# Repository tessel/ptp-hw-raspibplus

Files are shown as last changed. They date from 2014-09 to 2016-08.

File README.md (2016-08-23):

**[UNMAINTAINED] This library does not have a maintainer. The source code and repository will be kept at this URL indefinitely. If you'd like to help maintain this codebase, create an issue on this repo explaining why you'd like to become a maintainer and tag @tessel/maintainers in the body.**

ptp-hw-raspibplus
==================
Hardware adaptor to allow Tessel modules to be used with a Raspberry Pi B+ in conjunction with the Portable Tessel Platform (PTP).

Designs in KiCad.

### License

Copyright 2014 Technical Machine, Inc.
CC-BY-SA

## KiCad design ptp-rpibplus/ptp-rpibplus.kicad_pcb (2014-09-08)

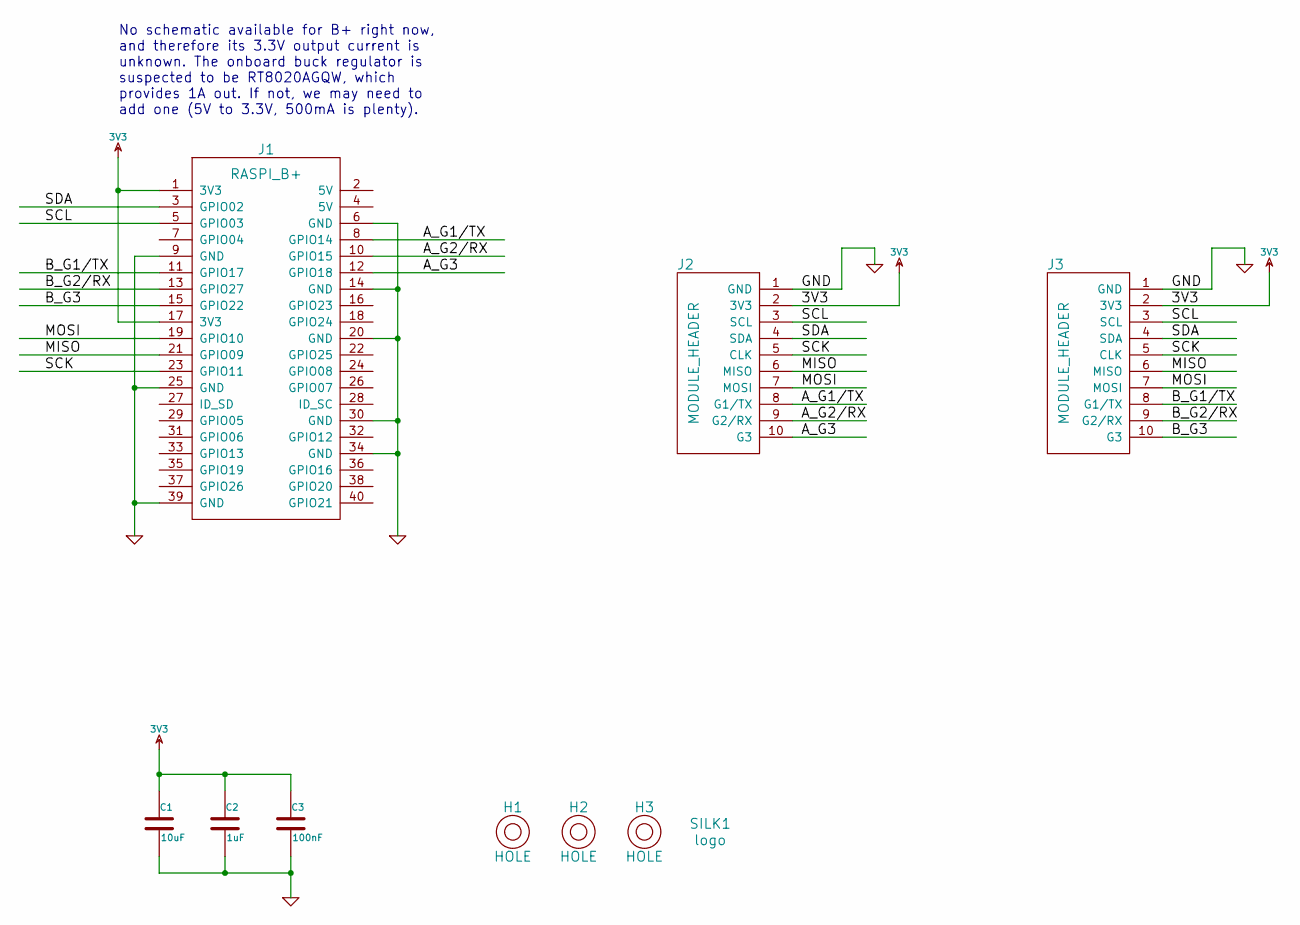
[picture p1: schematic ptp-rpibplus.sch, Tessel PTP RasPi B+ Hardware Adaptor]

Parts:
C1: 10uF; c_0805
C2: 1uF; c_0402
C3: 100nF; c_0402
H1, H2, H3: HOLE; HOLE-2.75mm-6.2mm
J1: RASPI_B+; Pin_Header_Straight_2x20
J2, J3: MODULE_HEADER; MODULE_HEADER_TESSEL
SILK1: logo; PTP-RPI-LOGO

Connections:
3V3: C1.1, C2.1, C3.1, J1.1 (3V3), J1.17 (3V3), J2.2 (3V3), J3.2 (3V3)
/A_G1/TX: J1.8 (GPIO14), J2.8 (G1/TX)
/A_G2/RX: J1.10 (GPIO15), J2.9 (G2/RX)
/A_G3: J1.12 (GPIO18), J2.10 (G3)
/B_G1/TX: J1.11 (GPIO17), J3.8 (G1/TX)
/B_G2/RX: J1.13 (GPIO27), J3.9 (G2/RX)
/B_G3: J1.15 (GPIO22), J3.10 (G3)
/MISO: J1.21 (GPIO09), J2.6 (MISO), J3.6 (MISO)
/MOSI: J1.19 (GPIO10), J2.7 (MOSI), J3.7 (MOSI)
/SCK: J1.23 (GPIO11), J2.5 (CLK), J3.5 (CLK)
/SCL: J1.5 (GPIO03), J2.3 (SCL), J3.3 (SCL)
/SDA: J1.3 (GPIO02), J2.4 (SDA), J3.4 (SDA)
GND: C1.2, C2.2, C3.2, J1.6 (GND), J1.9 (GND), J1.14 (GND), J1.20 (GND), J1.25 (GND), J1.30 (GND), J1.34 (GND), J1.39 (GND), J2.1 (GND), J3.1 (GND)

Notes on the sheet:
No schematic available for B+ right now, and therefore its 3.3V output current is unknown. The onboard buck regulator is suspected to be RT8020AGQW, which provides 1A out. If not, we may need to add one (5V to 3.3V, 500mA is plenty).

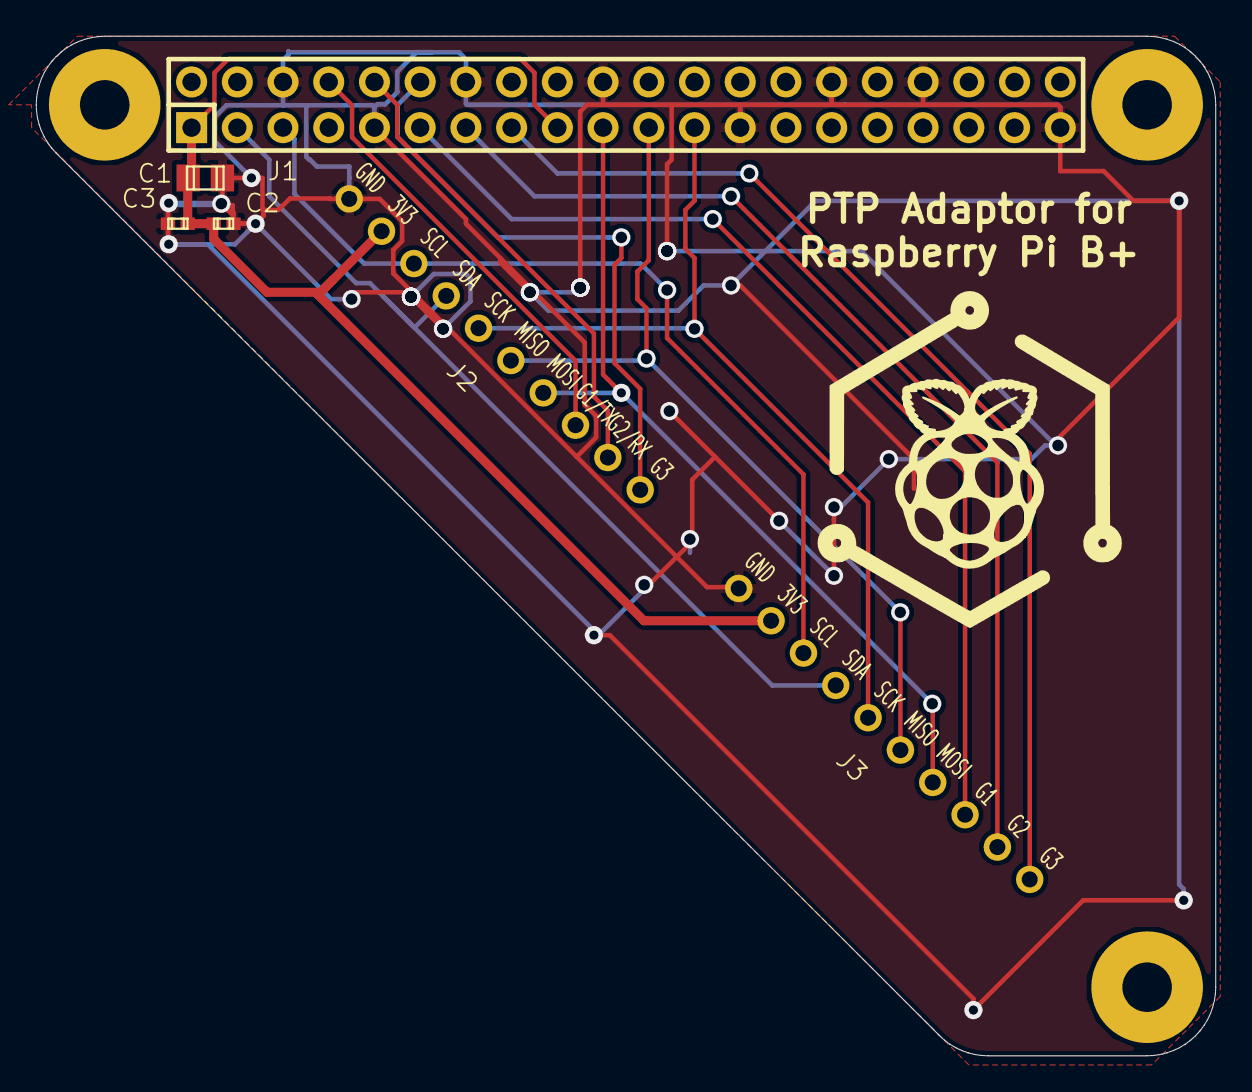
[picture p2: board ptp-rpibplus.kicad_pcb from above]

Board: 2 copper layers, 65.5 x 56.6 mm, 10 parts (0 on the bottom side), 13 nets.

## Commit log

2014-08-20 raspi module for ptp
    [tessel-raspi-b-plus.brd, tessel-raspi-b-plus.sch]
2014-08-22 added silkscreen text
    fixed repo
    Create README.md
    [tessel-raspi-b-plus.brd]
2014-09-05 wipe for kicad
    [tessel-raspi-b-plus.brd, tessel-raspi-b-plus.sch]
2014-09-05 started kicad project, schem
    [ptp-rpibplus.sch]
2014-09-05 parts in schematic, gotta do footprints
2014-09-05 schematic first pass
    [ptp-rpibplus.sch]
2014-09-05 netlist, annotation
    [ptp-rpibplus.sch]
2014-09-05 board file exists, components are all on it...rpi silk is no good
    [ptp-rpibplus.kicad_pcb]
2014-09-05 better silk for rpi header
    [ptp-rpibplus.kicad_pcb]
2014-09-05 close to refresh
    [ptp-rpibplus.kicad_pcb, ptp-rpibplus.sch]
2014-09-05 note about 3.3 rail, updated silk
    [ptp-rpibplus.kicad_pcb, ptp-rpibplus.sch]
2014-09-05 ...at least the board has mount holes now
    [ptp-rpibplus.kicad_pcb, ptp-rpibplus.sch]
2014-09-05 how did the pcb files not get added?
    [ptp-rpibplus.kicad_pcb]
2014-09-05 positioning things is hard
    [ptp-rpibplus.kicad_pcb]
2014-09-05 started routing, decided to pursue parallel instead
    [ptp-rpibplus.kicad_pcb]
2014-09-05 mostly happy. power and ground left.
    [ptp-rpibplus.kicad_pcb, ptp-rpibplus.sch]
2014-09-06 really really close
    [ptp-rpibplus.kicad_pcb]
2014-09-06 stupid not-polygons are stupid
    [ptp-rpibplus.kicad_pcb]
2014-09-06 silk tweaks to refdes
    [ptp-rpibplus.kicad_pcb]
2014-09-06 10mil pour clear
    [ptp-rpibplus.kicad_pcb]
2014-09-06 drc pass ...stupid vias
    [ptp-rpibplus.kicad_pcb]
2014-09-06 pour tweaks
    [ptp-rpibplus.kicad_pcb]
2014-09-08 added ptp rpib+ logo, board dimensions, updated gerbers
    [ptp-rpibplus-B_Cu.gbl, ptp-rpibplus-B_Mask.gbs, ptp-rpibplus-Edge_Cuts.gbr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]
2014-09-08 gerber zip

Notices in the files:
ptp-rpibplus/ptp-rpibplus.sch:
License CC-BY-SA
